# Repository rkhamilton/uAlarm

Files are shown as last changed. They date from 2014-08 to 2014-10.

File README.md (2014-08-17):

Ultimate Alarm Clock
====================
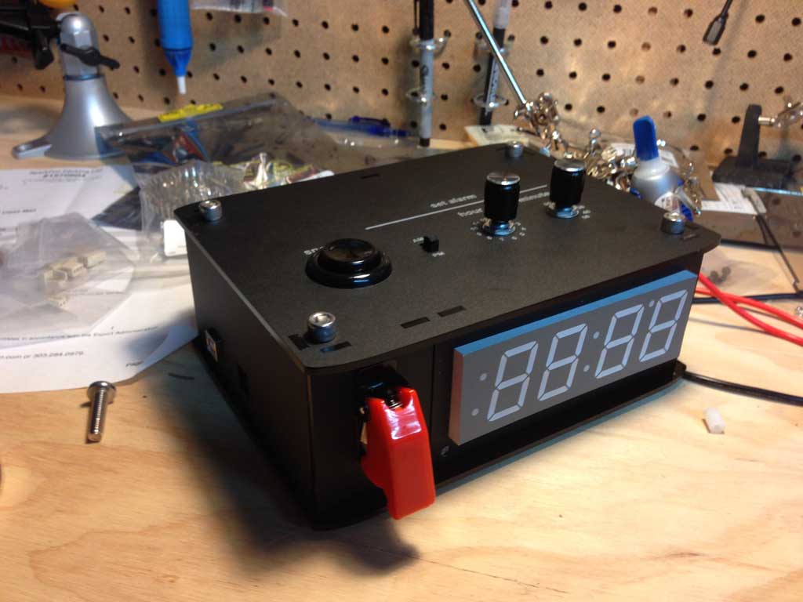
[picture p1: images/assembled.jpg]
Alarm Clock


Everybody who gets into Arduino makes a clock, and this one is mine. The unique attributes of my clock are:
- Time is synchronized with UTC via a GPS module
- Location is determined from the GPS, and the local time zone is identified (no internet connection needed)
- If the current location respects daylight savings time, it is correctly applied
- The 7-Segment LED display is automatically dimmed based on ambient light level. The min and max brightness are tunable with knobs
- The alarm time is set using rotary switches, which lets you directly set the time instead of repeatedly pressing a button
- It uses a custom PCB that sits like a mini-shield on top of an Arduino Mega 2560. There is a second micro-shield as an audio amplifier to correct the low audio volume supplied by the main board.
- The whole package is in a custom laser cut enclosure with painted, engraved labels
- It has a funny missile-switch toggle for turning the alarm on and off

#Acknowledgments
* [Timezone](https://github.com/JChristensen/Timezone)
* [TinyGPS++](http://arduiniana.org/libraries/tinygpsplus/)

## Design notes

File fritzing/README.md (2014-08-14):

This was my first project making my own PCB and I made a mess of it. The "- mega" file shows the actual logical layout of the project. I struggled to translate that into headers and wires, and ended up with the "- PCB3" file which generated the gerbers.

I also discovered that I didn't get enough power into my speaker using the 50 mA power from the Arduino mega PWM signal, so I created a separate small audio breakout board which fits into the 5V pins on the Mega.

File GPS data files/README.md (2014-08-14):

This is the US cities15000 data from geonames.org. In my GPS location code I find the location closest to the clock's coordinates, and look up the timezone of that location, and whether it respects daylight savings time.

In order to fit the dataset into the memory of an Arduino Mega, I trimmed the dataset down by eliminating any locations which are far from the edges of a timezone border. When finding the closest city, it only matters that we find a location within the same timezone, so center city locations are redundant.

The code and locations used are in the uAlarm.ino file itself. I plan to refactor that functionality into a library later but for now it's just baked into the main project.

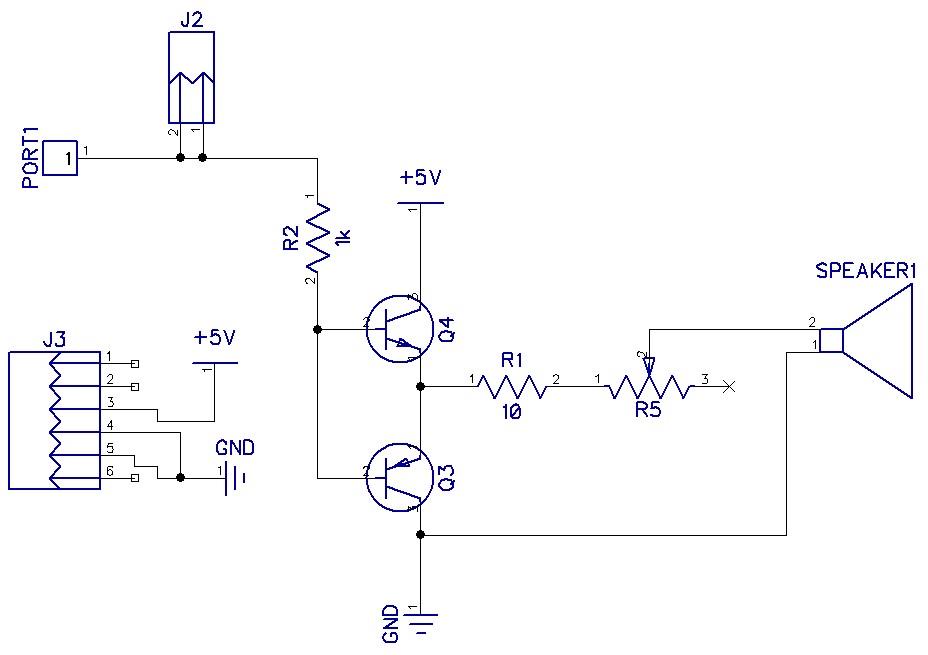
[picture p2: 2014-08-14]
diptrace/uAlarm-audio-schematic.jpg

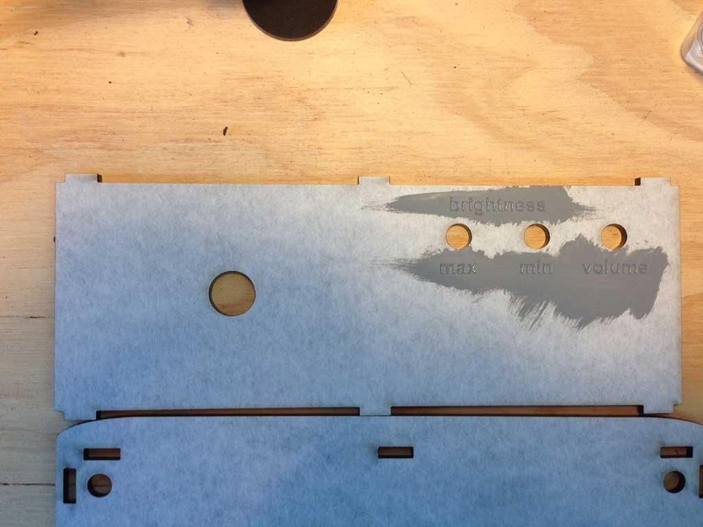
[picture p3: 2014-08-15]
images/back-plate-painted.jpg

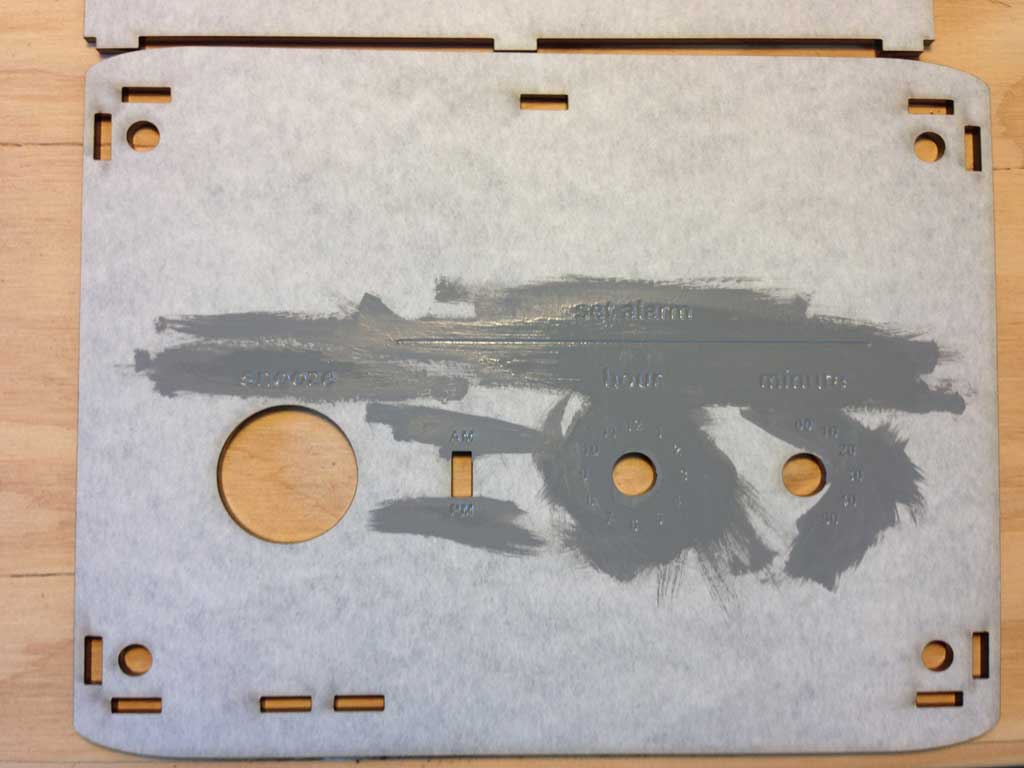
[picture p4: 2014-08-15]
images/top-plate-painted.jpg

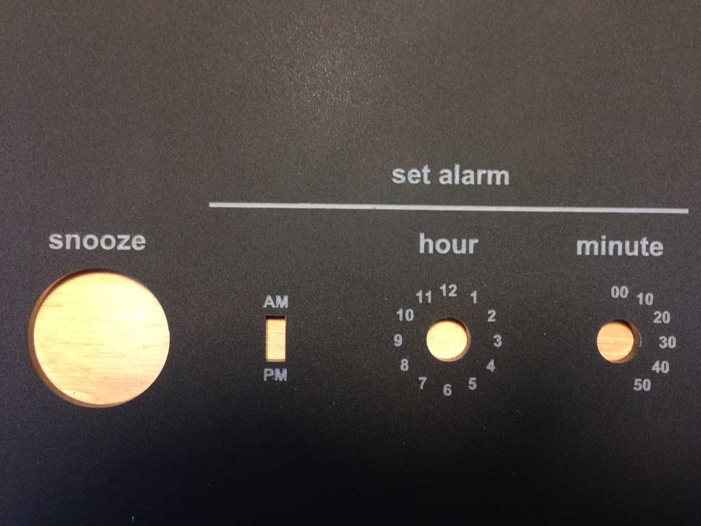
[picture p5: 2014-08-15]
images/top-plate.jpg

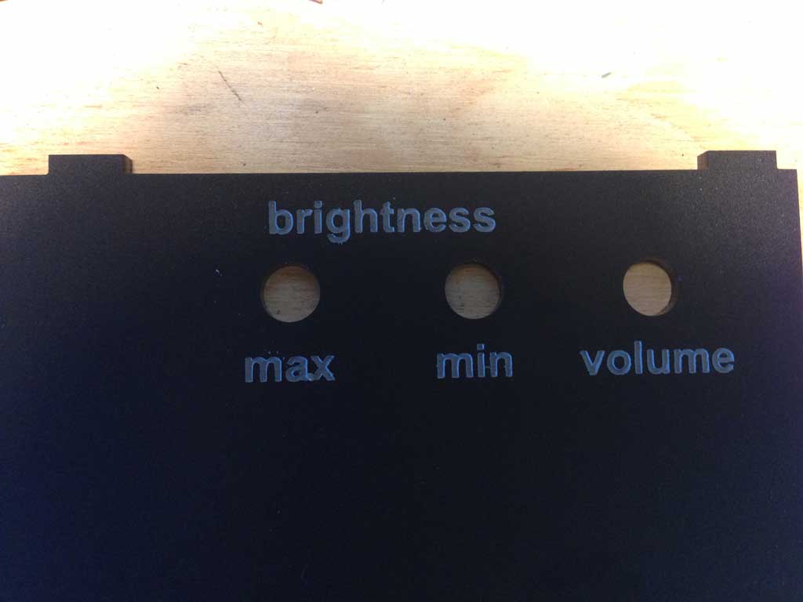
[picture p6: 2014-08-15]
images/back-plate.jpg

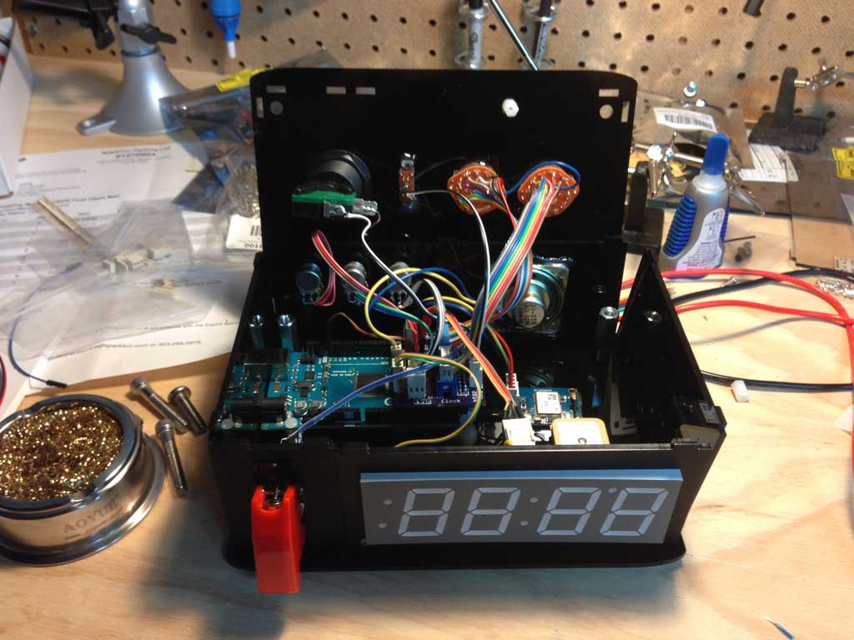
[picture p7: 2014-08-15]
images/open.jpg

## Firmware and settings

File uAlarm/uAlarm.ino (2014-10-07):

/*
 * uAlarm.ino
 *
 * Created: 7/18/2014 1:33:23 PM
 * Author: Ryan Hamilton
 */ 

#include "pitches.h"
#include "Timezone.h"
#include "TinyGPS++.h"
#include "Time.h"
#include "Streaming.h"
#include "GPSTimeZoneLookup.h" 
#include "Flash.h"

//for the Adafruit 7-segment display I2C backpack
#include <Wire.h>
#include <Adafruit_LEDBackpack.h>
#include <Adafruit_GFX.h>

//#define DEBUG
//#define DEBUG_FAKE_GPS
//#define DEBUG_PRINT_BRIGHTNESS
//#define DEBUG_PRINT_LOOP_SPEED
//#define DEBUG_TEST_TONE

#define GPS_TIME_UPDATE_INTERVAL_SECS 10
#define SNOOZE_DURATION_MINS 5

// define pins
//buttons
const byte alarmAMPMPin = 49;
const byte snoozePin = 43;
const byte alarmOnPin = 33;
//LCD control
const byte LCDminPin = A9;
const byte LCDmaxPin = A10;
const byte photoCellPin = A8;
const byte LCDSDApPin = 20;
const byte LCDSCLPin = 21;
//speaker
const byte speakerPin = 11;
//set alarm hour rotary switch
const byte setAlarmHour1Pin = 34;
const byte setAlarmHour2Pin = 23;
const byte setAlarmHour3Pin = 32;
const byte setAlarmHour4Pin = 22;
const byte setAlarmHour5Pin = 30;
const byte setAlarmHour6Pin = 24;
const byte setAlarmHour7Pin = 28;
const byte setAlarmHour8Pin = 26;
const byte setAlarmHour9Pin = 38;
const byte setAlarmHour10Pin = 53;
const byte setAlarmHour11Pin = 36;
const byte setAlarmHour12Pin = 40;
//set alarm minute rotary switch
const byte setAlarmMin00Pin = 48;
const byte setAlarmMin10Pin = 52;
const byte setAlarmMin20Pin = 46;
const byte setAlarmMin30Pin = 50;
const byte setAlarmMin40Pin = 44;
const byte setAlarmMin50Pin = 42;

//GPS - GPS is connected to hardware serial1 (TX on D18, RX on D19). Just read Serial1.begin(9600)
TinyGPSPlus gps; //TinyGPS++ object

boolean locationFound = false;

time_t nextDisplay = 0; // when to next update the numeric display
#define DISPLAY_UPDATE_INTERVAL 1 // update the display every one second
#define DISPLAY_ALARM_TIME_DURATION 5 // when the alarm time is displayed, show it for this many seconds

boolean alarmOn;
byte alarmHour = 12; // 24 hour time
byte alarmMin = 0;
//boolean alarmAMPM = true; // false == AM, true == PM
boolean snoozePressed = false;
boolean currentlyAlarming = false;

//Timezone library setup
TimeChangeRule timeChangeRuleStart;
TimeChangeRule timeChangeRuleStop;

#ifdef DEBUG_FAKE_GPS
// A sample NMEA stream.
const char *gpsStream =
"$GPRMC,045103.000,A,3014.1984,N,09749.2872,W,0.67,161.46,030913,,,A*7C\r\n"
"$GPGGA,045104.000,3014.1985,N,09749.2873,W,1,09,1.2,211.6,M,-22.5,M,,0000*62\r\n"
"$GPRMC,045200.000,A,3014.3820,N,09748.9514,W,36.88,65.02,030913,,,A*77\r\n"
"$GPGGA,045201.000,3014.3864,N,09748.9411,W,1,10,1.2,200.8,M,-22.5,M,,0000*6C\r\n"
"$GPRMC,045251.000,A,3014.4275,N,09749.0626,W,0.51,217.94,030913,,,A*7D\r\n"
"$GPGGA,045252.000,3014.4273,N,09749.0628,W,1,09,1.3,206.9,M,-22.5,M,,0000*6F\r\n";
#endif

//7 segment LCD display setup
Adafruit_7segment sevenSegmentDisplay = Adafruit_7segment();

// display modes
typedef enum {
    LCDTime, LCDAlarm
} LCDMode;
LCDMode currentMode = LCDTime;

void setup() {
    //switches and buttons
    pinMode(alarmAMPMPin, INPUT_PULLUP);
    pinMode(snoozePin, INPUT_PULLUP);
    pinMode(alarmOnPin, INPUT_PULLUP);

    //set alarm hour rotary switch
    pinMode(setAlarmHour1Pin, INPUT_PULLUP);
    pinMode(setAlarmHour2Pin, INPUT_PULLUP);
    pinMode(setAlarmHour3Pin, INPUT_PULLUP);
    pinMode(setAlarmHour4Pin, INPUT_PULLUP);
    pinMode(setAlarmHour5Pin, INPUT_PULLUP);
    pinMode(setAlarmHour6Pin, INPUT_PULLUP);
    pinMode(setAlarmHour7Pin, INPUT_PULLUP);
    pinMode(setAlarmHour8Pin, INPUT_PULLUP);
    pinMode(setAlarmHour9Pin, INPUT_PULLUP);
    pinMode(setAlarmHour10Pin, INPUT_PULLUP);
    pinMode(setAlarmHour11Pin, INPUT_PULLUP);
    pinMode(setAlarmHour12Pin, INPUT_PULLUP);

    //set alarm minute rotary switch
    pinMode(setAlarmMin00Pin, INPUT_PULLUP);
    pinMode(setAlarmMin10Pin, INPUT_PULLUP);
    pinMode(setAlarmMin20Pin, INPUT_PULLUP);
    pinMode(setAlarmMin30Pin, INPUT_PULLUP);
    pinMode(setAlarmMin40Pin, INPUT_PULLUP);
    pinMode(setAlarmMin50Pin, INPUT_PULLUP);

    //speaker
    pinMode(speakerPin, OUTPUT);

    //LCD control
    pinMode(LCDminPin, INPUT);
    pinMode(LCDmaxPin, INPUT);
    pinMode(photoCellPin, INPUT);
    pinMode(LCDSDApPin, INPUT);
    pinMode(LCDSCLPin, INPUT);


    //turn on the display and set it to say "GPS"
    //TODO

    //communicate output to a PC
    Serial.begin(9600);

    #ifdef DEBUG_FAKE_GPS
    while (*gpsStream) if (gps.encode(*gpsStream++)) displayGPSInfo();
    #else
    Serial1.begin(9600);
    #endif

    //I2C communication with display at address 0x70;
    sevenSegmentDisplay.begin(0x70);
    sevenSegmentDisplay.print(1200);
    sevenSegmentDisplay.writeDisplay();
    sevenSegmentDisplay.blinkRate(3);
    sevenSegmentDisplay.setBrightness(0);
}
void loop() {
    static unsigned long loopCount = 0;
    loopCount++;

    readGPS();
    
    //the first time we identify our location, calculate the time zone offset
    if (!locationFound && gps.location.isValid()) {
        locationFound = true;
        Serial.println("loop: first location lock");
        //based on our location, determine our GMT offset, and whether our location uses DST
        setTimeZoneAndDST(gps.location.lat(), gps.location.lng());
        //stop blinking the display
        sevenSegmentDisplay.blinkRate(0);
        //set up sync provider for Time.h
        setSyncProvider(gpsTimeSync);
        setSyncInterval(GPS_TIME_UPDATE_INTERVAL_SECS);
        setTime(gpsTimeSync());
        delay(10);
    }

    readSwitchesUpdateAlarmTime();

    #ifdef DEBUG_TEST_TONE
        if(alarmOn) {
            startAlarm();
        } else {stopAlarm();}
    #endif
    
    //if the alarm is turned on
    if(alarmOn) {
        //check to see if it is currently time to trigger the alarm
        if(isTimeToAlarm()) startAlarm();
        if(currentlyAlarming){
            playAlarmTone();
            //if it is currently alarming see if someone hit snooze and if so act on it
            if(snoozePressed) hitSnooze();
        }
    }
    else { //alarm switch is off
        if(currentlyAlarming) stopAlarm();
    }

    //show the right stuff on the LCD
    switch (currentMode) {
        case LCDTime:
            //display the current clock time based on GPS GMT, time zone and DST status
            if(timeStatus() != timeNotSet)    
            {
                if( now() >= nextDisplay ) {//update the display only if the time has changed by one second
                    nextDisplay = now() + DISPLAY_UPDATE_INTERVAL;
                    digitalClockSerialDisplay();
                    time_t  lt = calcLocalTime(now());
                    writeTimeDisplay(hour(lt),minute(lt),alarmOn);
                }
            }        
        break;
        case LCDAlarm: // display selected alarm time for a few seconds
            nextDisplay = now() + DISPLAY_ALARM_TIME_DURATION;
            currentMode = LCDTime;
            digitalClockSerialDisplay();
            writeTimeDisplay(alarmHour,alarmMin,true);
    }

#ifdef DEBUG_PRINT_LOOP_SPEED
    if((loopCount % 10000)==0){
        digitalClockSerialDisplay();
        static unsigned long lastMillis = 0;
        Serial.print("loops per sec: ");
        Serial.println(10000000/(millis()-lastMillis));
        lastMillis = millis();
    }  
#endif 

}
void setTimeZoneAndDST(float myLat, float myLong) {
    Serial.print("setTimeZoneAndDST: coordinates: ");
    Serial.print(myLat);
    Serial.print(", ");
    Serial.println(myLong);

    GPSTimeZoneLookup tz(myLat, myLong);

    int myGMTOffset = tz.GMTOffset;
    boolean myLocationUsesDST = tz.implementsDST;

    Serial.print("    identified time zone: ");
    switch(myGMTOffset){
        case -10: //Pacific/Honolulu
        Serial.println("US Hawaii?Aleutian Time Zone (Honolulu)");
        timeChangeRuleStart.week    = Second;
        timeChangeRuleStart.dow     = Sun;
        timeChangeRuleStart.month   = Mar;
        timeChangeRuleStart.hour    = 2;
        timeChangeRuleStart.offset  = -600;

        timeChangeRuleStop.week    = First;
        timeChangeRuleStop.dow     = Sun;
        timeChangeRuleStop.month   = Nov;
        timeChangeRuleStop.hour    = 2;
        timeChangeRuleStop.offset  = -600;
        break;
        case -9: //America/Anchorage
        Serial.println("US Alaska Time Zone (Anchorage)");
        timeChangeRuleStart.week    = Second;
        timeChangeRuleStart.dow     = Sun;
        timeChangeRuleStart.month   = Mar;
        timeChangeRuleStart.hour    = 2;
        timeChangeRuleStart.offset  = -480;

        timeChangeRuleStop.week    = First;
        timeChangeRuleStop.dow     = Sun;
        timeChangeRuleStop.month   = Nov;
        timeChangeRuleStop.hour    = 2;
        timeChangeRuleStop.offset  = -540;
        break;
        case -8: //America/Los_Angeles
        Serial.println("US Pacific Time Zone (Las Vegas, Los Angeles)");
        timeChangeRuleStart.week    = Second;
        timeChangeRuleStart.dow     = Sun;
        timeChangeRuleStart.month   = Mar;
        timeChangeRuleStart.hour    = 2;
        timeChangeRuleStart.offset  = -420;

        timeChangeRuleStop.week    = First;
        timeChangeRuleStop.dow     = Sun;
        timeChangeRuleStop.month   = Nov;
        timeChangeRuleStop.hour    = 2;
        timeChangeRuleStop.offset  = -480;
        break;
        case -7: //America/Phoenix or America/Denver
        if (myLocationUsesDST) {
            Serial.println("US Mountain Time Zone (Denver, Salt Lake City)");
            timeChangeRuleStart.week    = Second;
            timeChangeRuleStart.dow     = Sun;
            timeChangeRuleStart.month   = Mar;
            timeChangeRuleStart.hour    = 2;
            timeChangeRuleStart.offset  = -360;

            timeChangeRuleStop.week    = First;
            timeChangeRuleStop.dow     = Sun;
            timeChangeRuleStop.month   = Nov;
            timeChangeRuleStop.hour    = 2;
            timeChangeRuleStop.offset  = -420;
        }
        else {
            Serial.println("Arizona is US Mountain Time Zone but does not use DST");
            timeChangeRuleStart.week    = Second;
            timeChangeRuleStart.dow     = Sun;
            timeChangeRuleStart.month   = Mar;
            timeChangeRuleStart.hour    = 2;
            timeChangeRuleStart.offset  = -420;

            timeChangeRuleStop.week    = First;
            timeChangeRuleStop.dow     = Sun;
            timeChangeRuleStop.month   = Nov;
            timeChangeRuleStop.hour    = 2;
            timeChangeRuleStop.offset  = -420;
        }
        break;
        case -6: //America/Chicago - US Central Time Zone (Chicago, Houston)
        Serial.println("US Central Time Zone (Chicago, Houston)");
        timeChangeRuleStart.week    = Second;
        timeChangeRuleStart.dow     = Sun;
        timeChangeRuleStart.month   = Mar;
        timeChangeRuleStart.hour    = 2;
        timeChangeRuleStart.offset  = -300;

        timeChangeRuleStop.week    = First;
        timeChangeRuleStop.dow     = Sun;
        timeChangeRuleStop.month   = Nov;
        timeChangeRuleStop.hour    = 2;
        timeChangeRuleStop.offset  = -360;
        break;
        case -5: //America/New_York
        Serial.println("US Eastern Time Zone (New York, Detroit)");
        timeChangeRuleStart.week    = Second;
        timeChangeRuleStart.dow     = Sun;
        timeChangeRuleStart.month   = Mar;
        timeChangeRuleStart.hour    = 2;
        timeChangeRuleStart.offset  = -240;

        timeChangeRuleStop.week    = First;
        timeChangeRuleStop.dow     = Sun;
        timeChangeRuleStop.month   = Nov;
        timeChangeRuleStop.hour    = 2;
        timeChangeRuleStop.offset  = -300;
        break;
        default:
        Serial.println("Not found! Offset from GMT outside range {-10 to -5}");
    }

    /*
    //set up local Timezone object instance
    Timezone tz(timeChangeRuleStart,timeChangeRuleStop);
    localTimeZone = &tz;
    
    Serial.print("    before TZ conversion: ");
    digitalClockDisplay();
    setTime(localTimeZone->toLocal(now()));
    Serial.print("    after TZ conversion: ");
    digitalClockDisplay();
    Serial.println();
    */
}
void writeTimeDisplay(byte hours, byte minutes, bool alarmIsSet) {
    // write to the LCD display
    //bit map for TRUE for turning on dots
    static const uint8_t lowerLeftDot = 0x04;
    static const uint8_t upperLeftDot = 0x08;
    static const uint8_t decimalPoint = 0x10;
    static const uint8_t colon = 0x02;
    uint8_t displayMask = colon;
        
    // hour is 1-24, convert to 12 hours with PM
    boolean PM = false;
    if (hours >= 12) PM = true;
    if (hours>12) hours -= 12;
    if (hours == 0) hours = 12;
    
    sevenSegmentDisplay.print(hours*100 + minutes);
    if(PM)          displayMask = displayMask | upperLeftDot;
    if(alarmIsSet)  displayMask = displayMask | lowerLeftDot;
    sevenSegmentDisplay.writeDigitRaw(2,displayMask);
    sevenSegmentDisplay.setBrightness(calcLEDBrightness());
    sevenSegmentDisplay.writeDisplay();
}
byte AlarmHourSwitchValue() {
    byte switchValue;
    static byte prevSwitchValue = 0;
    //set alarm hour rotary switch. Switch label values are 1,2,3,4,5,6,7,8,9,10,11,12. The number 12 switch position returns 0. If there is no position selected (switch is mid-twist) return the previous value.

    //switches have pullup resistors, so LOW == connected
    if (digitalRead(setAlarmHour1Pin) == LOW) {
        switchValue = 1;
    }
    else if (digitalRead(setAlarmHour2Pin) == LOW) {
        switchValue = 2;
    }
    else if (digitalRead(setAlarmHour3Pin) == LOW) {
        switchValue = 3;
    }
    else if (digitalRead(setAlarmHour4Pin) == LOW) {
        switchValue = 4;
    }
    else if (digitalRead(setAlarmHour5Pin) == LOW) {
        switchValue = 5;
    }
    else if (digitalRead(setAlarmHour6Pin) == LOW) {
        switchValue = 6;
    }
    else if (digitalRead(setAlarmHour7Pin) == LOW) {
        switchValue = 7;
    }
    else if (digitalRead(setAlarmHour8Pin) == LOW) {
        switchValue = 8;
    }
    else if (digitalRead(setAlarmHour9Pin) == LOW) {
        switchValue = 9;
    }
    else if (digitalRead(setAlarmHour10Pin) == LOW) {
        switchValue = 10;
    }
    else if (digitalRead(setAlarmHour11Pin) == LOW) {
        switchValue = 11;
    }
    else if (digitalRead(setAlarmHour12Pin) == LOW) {
        switchValue = 0;
    }
    else {
        switchValue = prevSwitchValue;
    }

    prevSwitchValue = switchValue;
    return switchValue;
}
byte AlarmMinSwitchValue() {
    byte switchValue;
    static byte prevSwitchValue = 0;
    //set alarm hour rotary switch. Switch label values are 00, 10, 20, 30, 40, 50. If there is no position selected (switch is mid-twist) return the previous value.

    //switches have pullup resistors, so LOW == connected
    if (digitalRead(setAlarmMin00Pin) == LOW) {
        switchValue = 0;
    }
    else if (digitalRead(setAlarmMin10Pin) == LOW) {
        switchValue = 1;
    }
    else if (digitalRead(setAlarmMin20Pin) == LOW) {
        switchValue = 2;
    }
    else if (digitalRead(setAlarmMin30Pin) == LOW) {
        switchValue = 3;
    }
    else if (digitalRead(setAlarmMin40Pin) == LOW) {
        switchValue = 4;
    }
    else if (digitalRead(setAlarmMin50Pin) == LOW) {
        switchValue = 5;
    }
    else {
        switchValue = prevSwitchValue;
    }


    prevSwitchValue = switchValue;
    return switchValue * 10;
}
void digitalClockSerialDisplay(){
    // digital clock display of the time
    Serial.print("digitalClockDisplay: UTC: ");
    displayTime(now());
    Serial.print(" local: ");
    displayTime(calcLocalTime(now()));
    Serial.print(" alarmOn: ");
    Serial.print(alarmOn);
    Serial.print(" alarmHour: ");
    Serial.print(alarmHour);
    Serial.print(" alarmMin: ");
    Serial.print(alarmMin);
    Serial.print(" currentlyAlarming: ");
    Serial.print(currentlyAlarming);
    Serial.println();
}
void printDigits(int digits) {
    // utility function for digital clock display: prints preceding colon and leading 0
    Serial.print(":");
    if(digits < 10)
    Serial.print('0');
    Serial.print(digits);
}
void displayGPSInfo() {
    // displays GPS coordinates and UTC
    Serial.print(F("Location: "));
    if (gps.location.isValid())
    {
        Serial.print(gps.location.lat(), 6);
        Serial.print(F(","));
        Serial.print(gps.location.lng(), 6);
    }
    else
    {
        Serial.print(F("INVALID"));
    }

    Serial.print(F("  UTC: "));
    if (gps.date.isValid())
    {
        Serial.print(gps.date.month());
        Serial.print(F("/"));
        Serial.print(gps.date.day());
        Serial.print(F("/"));
        Serial.print(gps.date.year());
    }
    else
    {
        Serial.print(F("INVALID"));
    }

    Serial.print(F(" "));
    if (gps.time.isValid())
    {
        if (gps.time.hour() < 10) Serial.print(F("0"));
        Serial.print(gps.time.hour());
        Serial.print(F(":"));
        if (gps.time.minute() < 10) Serial.print(F("0"));
        Serial.print(gps.time.minute());
        Serial.print(F(":"));
        if (gps.time.second() < 10) Serial.print(F("0"));
        Serial.print(gps.time.second());
        Serial.print(F("."));
        if (gps.time.centisecond() < 10) Serial.print(F("0"));
        Serial.print(gps.time.centisecond());
    }
    else
    {
        Serial.print(F("INVALID"));
    }

    Serial.println();
}
time_t gpsTimeSync() {
    //  returns time_t if avail from gps, else returns 0
    Serial.println("gpsTimeSync: time sync");
    
    //return gpsTimeToArduinoTime(); // return time only if updated recently by gps
    if (gps.date.isUpdated() && gps.time.isUpdated()) {
        Serial.println("    time data updated, update Time");
        return gpsTimeToTime_t(); // return time only if updated recently by gps
    }
    else {
        Serial.println("    time data not updated");
        #ifdef DEBUG
        return gpsTimeToTime_t();
        #else
        return 0;
        #endif
        
    }
    
}
time_t gpsTimeToTime_t() {
    // returns time_t from gps date and time in UTC
    tmElements_t tm;

    tm.Year = gps.date.year() - 1970;
    tm.Month = gps.date.month();
    tm.Day = gps.date.day();
    tm.Hour = gps.time.hour();
    tm.Minute = gps.time.minute();
    tm.Second = gps.time.second();

    #ifdef DEBUG //for debugging lets make it always 2 minutes before 7AM
    tm.Year = gps.date.year() - 1970;
    tm.Month = gps.date.month();
    tm.Day = gps.date.day();
    tm.Hour = 11;
    tm.Minute = 59;
    tm.Second = 40;
    #endif
    
    return makeTime(tm); //UTC
}
void startAlarm() {
    //turn on the alarm
    currentlyAlarming = true;
}
void stopAlarm() {
    //turn off the alarm
    currentlyAlarming = false;
    noTone(speakerPin);
}
void hitSnooze() {
    snoozePressed = false;
    //localAlarmTime = now() + SNOOZE_DURATION_SECS;
    stopAlarm();
    alarmMin = alarmMin + SNOOZE_DURATION_MINS;
    if (alarmMin == 60) {
        alarmMin = 0;
        alarmHour++;
    }
    if (alarmHour == 25) alarmHour = 0;
    Serial.print("hitSnooze: ");
    Serial.print(alarmHour);
    Serial.print(":");
    Serial.println(alarmMin);
}
void displayTime(time_t t) {
    // digital clock display of the time
    Serial.print(hour(t));
    printDigits(minute(t));
    printDigits(second(t));
    Serial.print(" ");
    Serial.print(month(t));
    Serial.print("/");
    Serial.print(day(t));
    Serial.print("/");
    Serial.print(year(t));
}
boolean isTimeToAlarm() {
    //compare local time hour and minutes to alarm settings. returns true if it is past time to alarm
    time_t   localTime = calcLocalTime(now());

    return (alarmHour == hour(localTime) && alarmMin == minute(localTime));
}
time_t calcLocalTime(time_t t) {
    //convert time_t from UTC to local time
    if (locationFound)
    {
        static Timezone localTimeZone(timeChangeRuleStart,timeChangeRuleStop);
        return localTimeZone.toLocal(t);
    }
    else
    {
        return t;
    }
}
void readSwitchesUpdateAlarmTime() {
    //if currently snoozing and someone changes a knob, stop snoozing and just use the knob alarm time. Otherwise if snoozing do not update alarm time (snooze set a new alarm)
    //any other time, just use the knob time
    
    // HMI state
    byte	hourSwitchVal;
    byte	minSwitchVal;
    static byte	prevHourSwitchVal = 255;
    static byte	preMinSwitchVal = 255;
    static boolean prevAlarmAMPM = false;
    boolean alarmOnSwitchVal;
    boolean alarmAMPM;
    
    //read all of the switches positions
    hourSwitchVal	= AlarmHourSwitchValue(); // noon == 0
    minSwitchVal	= AlarmMinSwitchValue();
    alarmAMPM = digitalRead(alarmAMPMPin);
    //if the alarm switch is flipped off then turn off the alarm
    alarmOnSwitchVal = (digitalRead(alarmOnPin)==LOW);
    
     
    if ((hourSwitchVal != prevHourSwitchVal)|| 
        (minSwitchVal != preMinSwitchVal)   || 
        (alarmAMPM != prevAlarmAMPM)        || 
        (!alarmOn && alarmOnSwitchVal) ) // someone deliberately changed a knob position
    {
        Serial << alarmOn << alarmOnSwitchVal << ":" << prevHourSwitchVal << preMinSwitchVal << prevAlarmAMPM << "-->";
        Serial << hourSwitchVal << minSwitchVal << alarmAMPM << endl;
       alarmHour = hourSwitchVal + 12 * (byte)alarmAMPM;
        alarmMin = minSwitchVal;
        prevHourSwitchVal = hourSwitchVal;
        preMinSwitchVal = minSwitchVal;
        prevAlarmAMPM = alarmAMPM;
        alarmOn = alarmOnSwitchVal;
        currentMode = LCDAlarm;
        Serial.println("values changed");
    }
    
    // if the alarm switch is turned off, always set alarm off
    if (!alarmOnSwitchVal)
    {
        alarmOn = false;
    }
    

    //only register a snooze press if the alarm is currently active
    if(currentlyAlarming && digitalRead(snoozePin)==LOW) snoozePressed = true;
}
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

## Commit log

2014-08-14 gerber files ordered on 05Jul14 from OSH Park
    [05Jul14.fzz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]
2014-08-14 ordered from OSH park
    [Ultimate Alarm Clock - for PCB3.fzz, Ultimate Alarm Clock - mega.fzz]
2014-08-14 raw and processed data used inside the main .ino
    [cities15000-US-tz.xlsx, cities15000.xlsx]
2014-08-14 .svg files used to design and order the enclosure
    Ordered from ponoko.com
2014-08-14 audio amplifier breakout board
    The original board didn't put out enough power for the speaker. This is
    a dedicated square wave amplifier board.
    [BoardOutline.gbr, Bottom.gbr, BottomDimension.gbr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]
2014-08-14 Added photo of assembled clock
